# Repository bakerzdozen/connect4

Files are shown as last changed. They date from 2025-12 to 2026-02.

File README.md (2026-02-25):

# connect4

## About

4-in-a-line ("Connect 4" by Hasbro) is a popular two-player table game played with red and yellow chips for player 1 and player 2, respectively. It is played on a 7x6 board, where the objective is to connect four of your coloured chips in a row - be that horizontal, vertical or diagonal. 

This project aims to recreate the joy of 4-in-a-line with a modern twist, allowing for solo play against the "computer" (a very basic algorithm). Both the hardware and firmware are included in this repository to allow you to create your own variants or to make the exact same one yourself!

Originally, this project was a Christmas gift for my family and friends, but I have now made it open-source so anyone can make their own, or modify it to make it even better!

## Making Your Own

If you intend to create your own, you will need - at very least - the following:

- STM Cube IDE
- Pre-compiled firmware
- Fully assembled circuit board (I recommend JLC PCB)

## Improvements

If you have suggestions for how to make this project better, please let me know! The best way is through creating your own branch and making the modifications you see fit. If they are sensible and enhance the project in some meaningful way, I will be happy to merge your modifications to the main branch!

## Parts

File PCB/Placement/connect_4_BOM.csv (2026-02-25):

Designator | Qty | Comment | Footprint | JLC Part Number
C101,C102,C103,C106,C111,C112,C113,C115 | 8 | 4.7u | Capacitor_SMD:C_0603_1608Metric | C69335
C104 | 1 | 47u | Capacitor_SMD:C_1206_3216Metric | C403725
C105 | 1 | 10n | Capacitor_SMD:C_0603_1608Metric | C1589
C107,C108,C109,C110,C114,C201,C202,C301,C302,C401,C402,C501,C502,C601,C602,C701,C702,C801,C802 | 19 | 100n | Capacitor_SMD:C_0603_1608Metric | C1591
D101,D102 | 2 | LED | Diode_SMD:D_0603_1608Metric | C126319
D201,D202,D203,D204,D205,D206,D301,D302,D303,D304,D305,D306,D401,D402,D403,D404,D405,D406,D501,D502,D503,D504,D505,D506,D601,D602,D603,D604,D605,D606,D701,D702,D703,D704,D705,D706,D801,D802,D803,D804,D805,D806 | 42 | LED | Diode_SMD:D_0603_1608Metric | C79636
D207,D208,D209,D210,D211,D212,D307,D308,D309,D310,D311,D312,D407,D408,D409,D410,D411,D412,D507,D508,D509,D510,D511,D512,D607,D608,D609,D610,D611,D612,D707,D708,D709,D710,D711,D712,D807,D808,D809,D810,D811,D812 | 42 | LED | Diode_SMD:D_0603_1608Metric | C122984
J101 | 1 | USB4105-GF-A | Custom:USB4105_GCT | C2765186
R101,R102,R104,R105,R106,R107,R108,R109,R110 | 9 | 5.1k | Resistor_SMD:R_0603_1608Metric | C105580
R103,R111,R201,R202,R203,R204,R205,R206,R207,R208,R209,R210,R211,R212,R301,R302,R303,R304,R305,R306,R307,R308,R309,R310,R311,R312,R401,R402,R403,R404,R405,R406,R407,R408,R409,R410,R411,R412,R501,R502,R503,R504,R505,R506,R507,R508,R509,R510,R511,R512,R601,R602,R603,R604,R605,R606,R607,R608,R609,R610,R611,R612,R701,R702,R703,R704,R705,R706,R707,R708,R709,R710,R711,R712,R801,R802,R803,R804,R805,R806,R807,R808,R809,R810,R811,R812 | 86 | 1.2k | Resistor_SMD:R_0603_1608Metric | C114605
SW101,SW102,SW103,SW104 | 4 | SW_Push | Button_Switch_SMD:SW_Push_1P1T_NO_CK_KSC9xxG | C2837531
U101 | 1 | AMS1117-3.3 | Package_TO_SOT_SMD:SOT-223-3_TabPin2 | C6186
U102 | 1 | STM32G431CBTx | Package_QFP:LQFP-48_7x7mm_P0.5mm | C529355
U201,U202,U301,U302,U401,U402,U501,U502,U601,U602,U701,U702,U801,U802 | 14 | 74HC594 | Package_SO:SOIC-16W_7.5x10.3mm_P1.27mm | C91727

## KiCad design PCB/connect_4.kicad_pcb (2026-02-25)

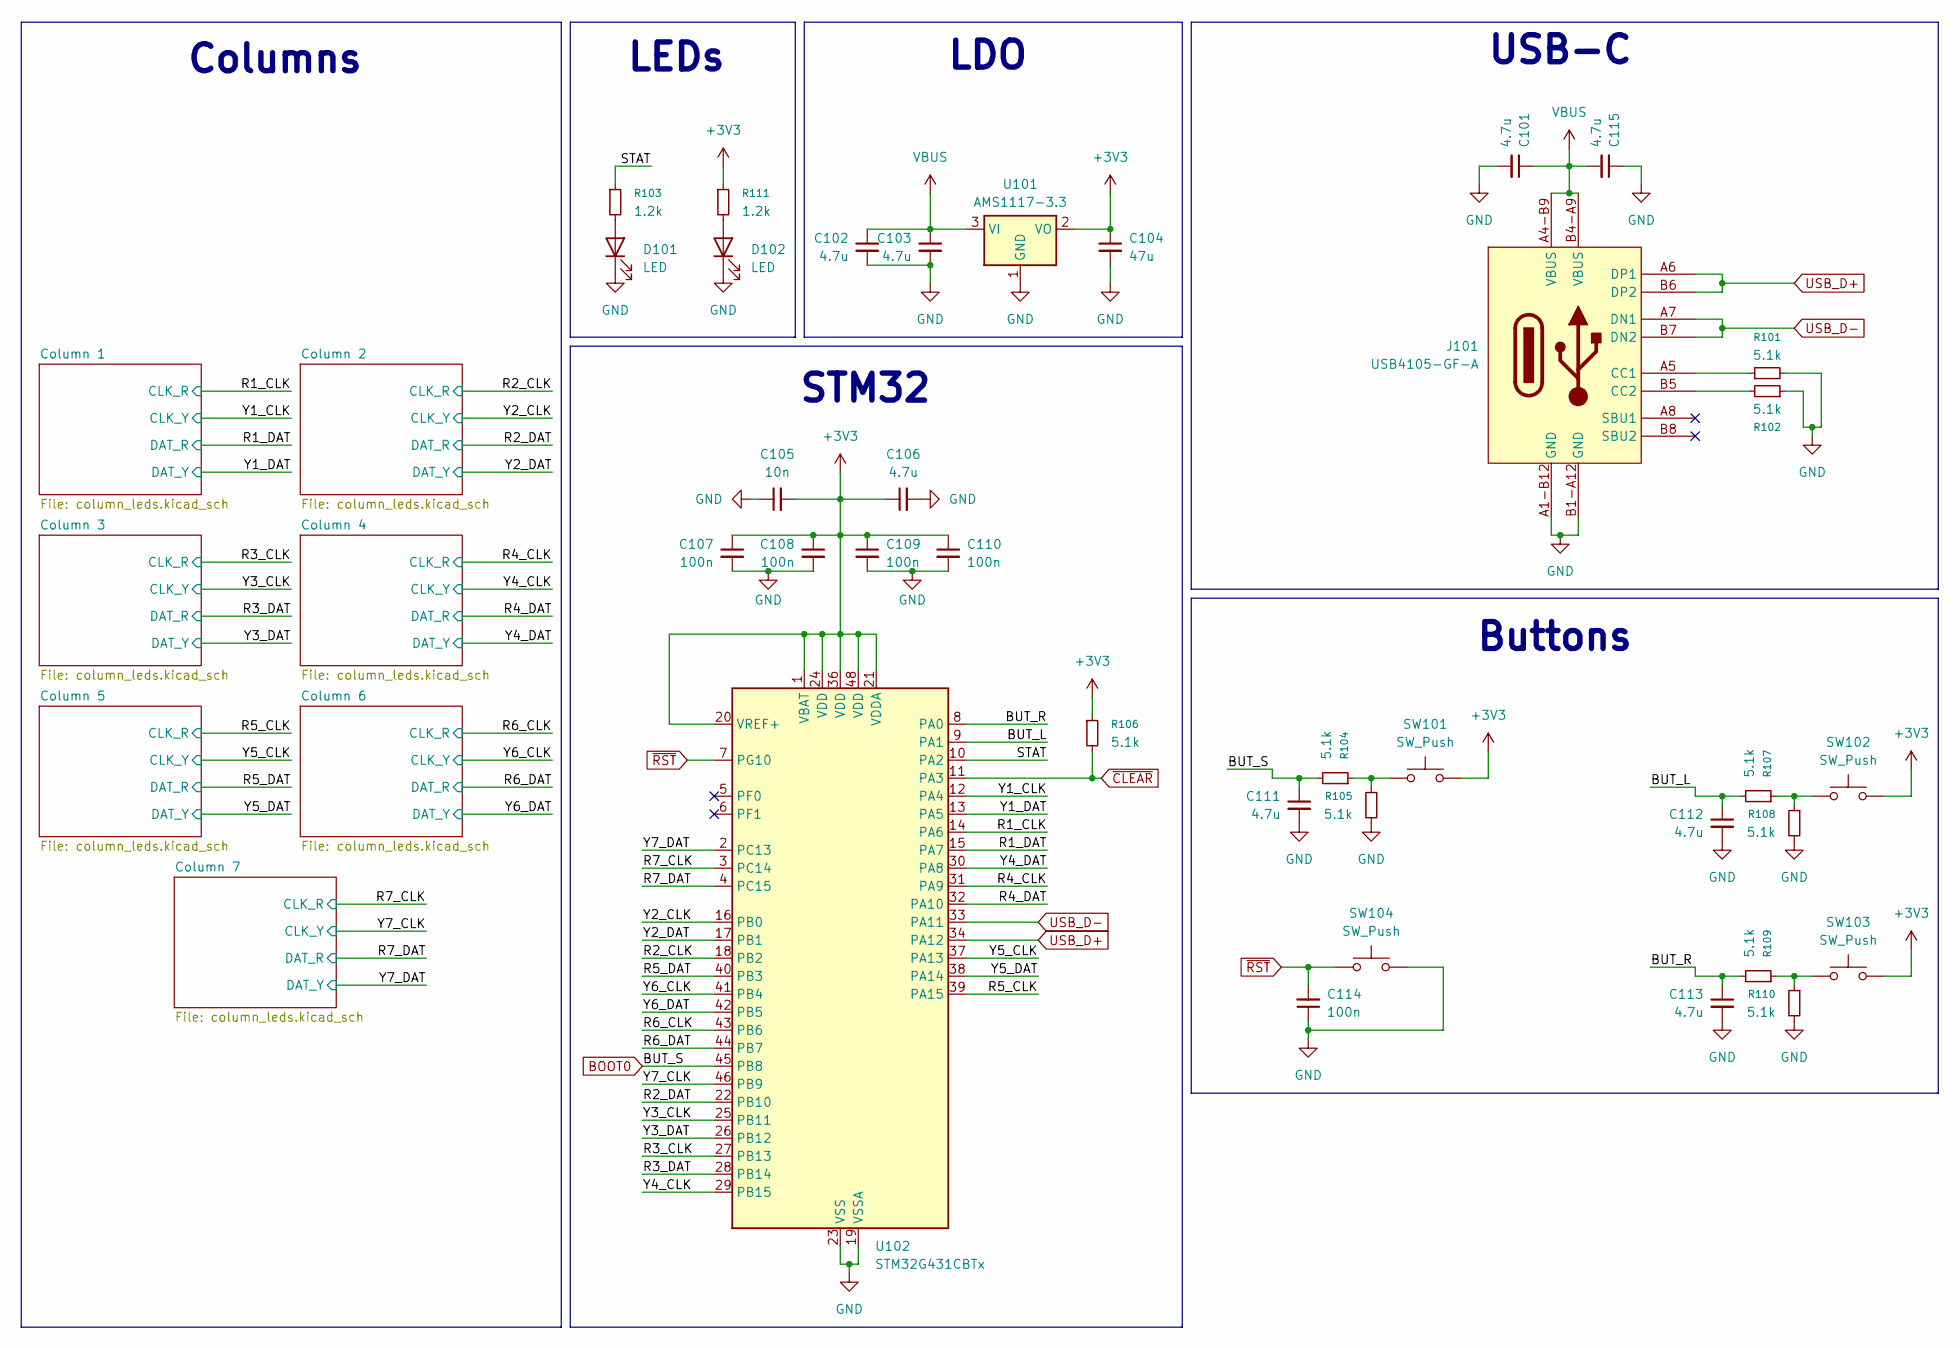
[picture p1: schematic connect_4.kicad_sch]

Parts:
C101, C102, C103, C106, C111, C112, C113, C115: 4.7u; C_0603_1608Metric; Manufacturer Part Number C69335
C104: 47u; C_1206_3216Metric; Manufacturer Part Number C403725
C105: 10n; C_0603_1608Metric; Manufacturer Part Number C1589
C107, C108, C109, C110, C114: 100n; C_0603_1608Metric; Manufacturer Part Number C1591
D101, D102: LED; D_0603_1608Metric; Manufacturer Part Number C126319
J101: USB4105-GF-A; USB4105_GCT; Manufacturer Part Number C2765186
R101, R102, R104, R105, R106, R107, R108, R109, R110: 5.1k; R_0603_1608Metric; Manufacturer Part Number C105580
R103, R111: 1.2k; R_0603_1608Metric; Manufacturer Part Number C114605
SW101, SW102, SW103, SW104: SW_Push; SW_Push_1P1T_NO_CK_KSC9xxG; Manufacturer Part Number C2837531
U101: AMS1117-3.3; SOT-223-3_TabPin2; Manufacturer Part Number C6186
U102: STM32G431CBTx; LQFP-48_7x7mm_P0.5mm; Manufacturer Part Number C529355

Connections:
+3V3: C104.1, C105.2, C106.1, C107.1, C108.1, C109.1, C110.1, R106.1, R111.1, SW101.2, SW102.2, SW103.2, U101.2 (VO), U102.1 (VBAT), U102.20 (VREF+), U102.21 (VDDA), U102.24 (VDD), U102.36 (VDD), U102.48 (VDD); also elsewhere on the board
/BUT_L: C112.1, R107.2, U102.9 (PA1)
/BUT_R: C113.1, R109.2, U102.8 (PA0)
/R1_CLK: U102.14 (PA6); also elsewhere on the board
/R1_DAT: U102.15 (PA7); also elsewhere on the board
/R2_CLK: U102.18 (PB2); also elsewhere on the board
/R2_DAT: U102.22 (PB10); also elsewhere on the board
/R3_CLK: U102.27 (PB13); also elsewhere on the board
/R3_DAT: U102.28 (PB14); also elsewhere on the board
/R4_CLK: U102.31 (PA9); also elsewhere on the board
/R4_DAT: U102.32 (PA10); also elsewhere on the board
/R5_CLK: U102.39 (PA15); also elsewhere on the board
/R5_DAT: U102.40 (PB3); also elsewhere on the board
/R6_CLK: U102.43 (PB6); also elsewhere on the board
/R6_DAT: U102.44 (PB7); also elsewhere on the board
/R7_CLK: U102.3 (PC14); also elsewhere on the board
/R7_DAT: U102.4 (PC15); also elsewhere on the board
/STAT: R103.1, U102.10 (PA2)
/Y1_CLK: U102.12 (PA4); also elsewhere on the board
/Y1_DAT: U102.13 (PA5); also elsewhere on the board
/Y2_CLK: U102.16 (PB0); also elsewhere on the board
/Y2_DAT: U102.17 (PB1); also elsewhere on the board
/Y3_CLK: U102.25 (PB11); also elsewhere on the board
/Y3_DAT: U102.26 (PB12); also elsewhere on the board
/Y4_CLK: U102.29 (PB15); also elsewhere on the board
/Y4_DAT: U102.30 (PA8); also elsewhere on the board
/Y5_CLK: U102.37 (PA13); also elsewhere on the board
/Y5_DAT: U102.38 (PA14); also elsewhere on the board
/Y6_CLK: U102.41 (PB4); also elsewhere on the board
/Y6_DAT: U102.42 (PB5); also elsewhere on the board
/Y7_CLK: U102.46 (PB9); also elsewhere on the board
/Y7_DAT: U102.2 (PC13); also elsewhere on the board
BOOT0: C111.1, R104.2, U102.45 (PB8)
GND: C101.2, C102.2, C103.2, C104.2, C105.1, C106.2, C107.2, C108.2, C109.2, C110.2, C111.2, C112.2, C113.2, C114.1, C115.1, D101.1 (K), D102.1 (K), J101.A1-B12 (GND), J101.B1-A12 (GND), R101.2, R102.1, R105.2, R108.2, R110.2, SW104.2, U101.1 (GND), U102.19 (VSSA), U102.23 (VSS), U102.35 (VSS), U102.47 (VSS); also elsewhere on the board
unnamed: D101.2 (A), R103.2
unnamed: D102.2 (A), R111.2
unnamed: J101.A5 (CC1), R101.1
unnamed: J101.B5 (CC2), R102.2
unnamed: R104.1, R105.1, SW101.1
unnamed: R107.1, R108.1, SW102.1
unnamed: R109.1, R110.1, SW103.1
USB_D+: J101.A6 (DP1), J101.B6 (DP2), U102.34 (PA12)
USB_D-: J101.A7 (DN1), J101.B7 (DN2), U102.33 (PA11)
VBUS: C101.1, C102.1, C103.1, C115.2, J101.A4-B9 (VBUS), J101.B4-A9 (VBUS), U101.3 (VI)
~CLEAR: R106.2, U102.11 (PA3); also elsewhere on the board
~RST: C114.2, SW104.1, U102.7 (PG10)

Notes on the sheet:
Buttons
USB-C
LDO
LEDs
STM32
Columns

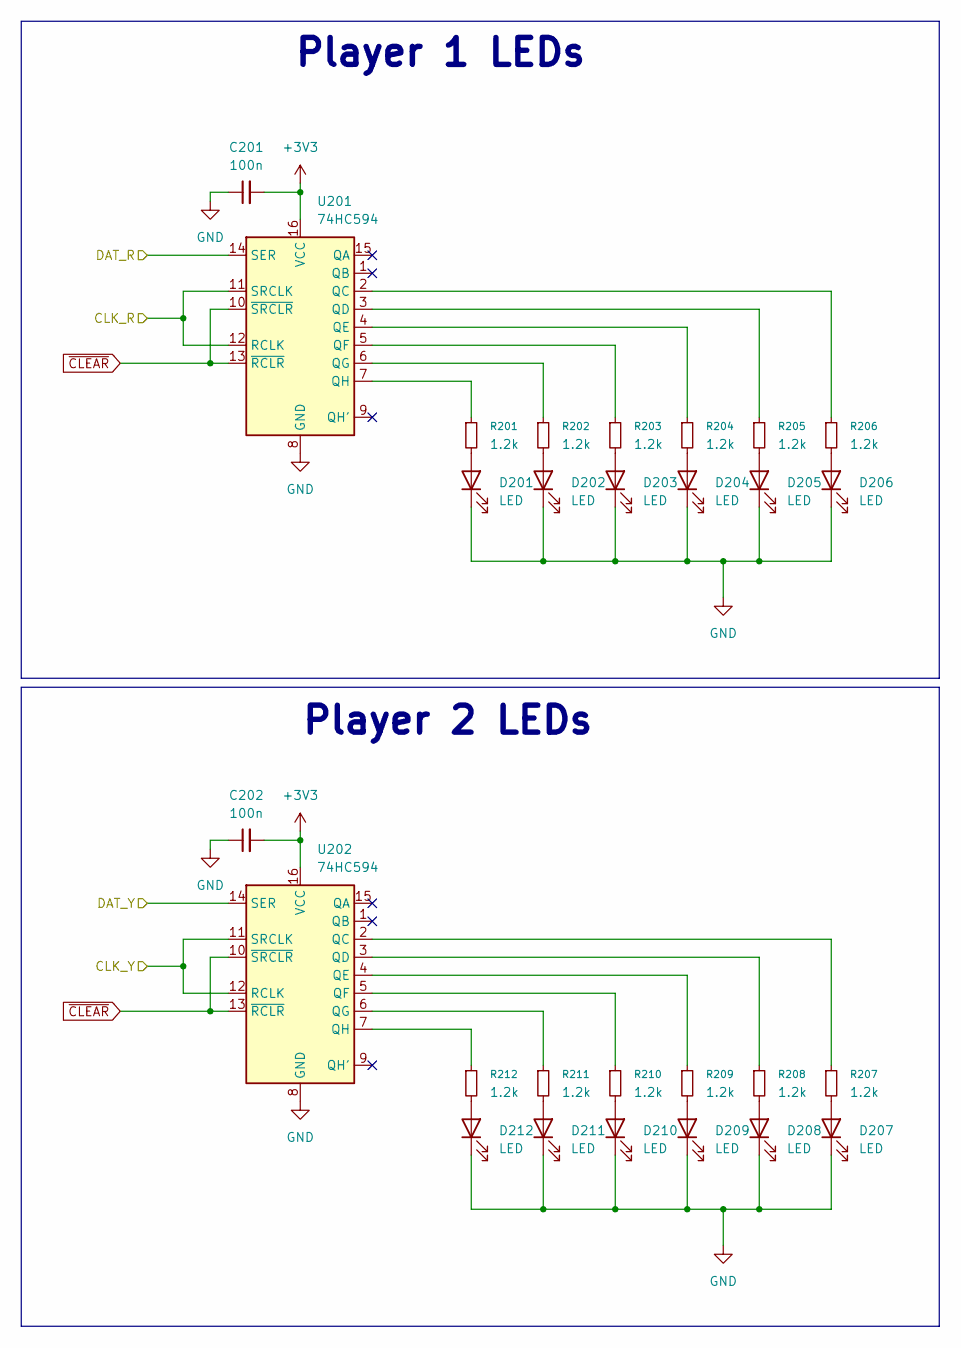
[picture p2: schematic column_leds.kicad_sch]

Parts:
C201, C202: 100n; C_0603_1608Metric; Manufacturer Part Number C1591
D201, D202, D203, D204, D205, D206: LED; D_0603_1608Metric; Manufacturer Part Number C79636
D207, D208, D209, D210, D211, D212: LED; D_0603_1608Metric; Manufacturer Part Number C122984
R201, R202, R203, R204, R205, R206, R207, R208, R209, R210, R211, R212: 1.2k; R_0603_1608Metric; Manufacturer Part Number C114605
U201, U202: 74HC594; SOIC-16W_5.3x10.2mm_P1.27mm; Manufacturer Part Number C91727

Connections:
+3V3: C201.2, C202.2, U201.16 (VCC), U202.16 (VCC); also elsewhere on the board
/R1_CLK: U201.11 (SRCLK), U201.12 (RCLK); also elsewhere on the board
/R1_DAT: U201.14 (SER); also elsewhere on the board
/Y1_CLK: U202.11 (SRCLK), U202.12 (RCLK); also elsewhere on the board
/Y1_DAT: U202.14 (SER); also elsewhere on the board
GND: C201.1, C202.1, D201.1 (K), D202.1 (K), D203.1 (K), D204.1 (K), D205.1 (K), D206.1 (K), D207.1 (K), D208.1 (K), D209.1 (K), D210.1 (K), D211.1 (K), D212.1 (K), U201.8 (GND), U202.8 (GND); also elsewhere on the board
unnamed: D201.2 (A), R201.2
unnamed: D202.2 (A), R202.2
unnamed: D203.2 (A), R203.2
unnamed: D204.2 (A), R204.2
unnamed: D205.2 (A), R205.2
unnamed: D206.2 (A), R206.2
unnamed: D207.2 (A), R207.2
unnamed: D208.2 (A), R208.2
unnamed: D209.2 (A), R209.2
unnamed: D210.2 (A), R210.2
unnamed: D211.2 (A), R211.2
unnamed: D212.2 (A), R212.2
unnamed: R206.1, U201.2 (QC)
unnamed: R205.1, U201.3 (QD)
unnamed: R204.1, U201.4 (QE)
unnamed: R203.1, U201.5 (QF)
unnamed: R202.1, U201.6 (QG)
unnamed: R201.1, U201.7 (QH)
unnamed: R207.1, U202.2 (QC)
unnamed: R208.1, U202.3 (QD)
unnamed: R209.1, U202.4 (QE)
unnamed: R210.1, U202.5 (QF)
unnamed: R211.1, U202.6 (QG)
unnamed: R212.1, U202.7 (QH)
~CLEAR: U201.10 (~SRCLR), U201.13 (~RCLR), U202.10 (~SRCLR), U202.13 (~RCLR); also elsewhere on the board

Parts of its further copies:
C301, C302, C401, C402, C501, C502, C601, C602, C701, C702, C801, C802: 100n; C_0603_1608Metric; Manufacturer Part Number C1591
D301, D302, D303, D304, D305, D306, D401, D402, D403, D404, D405, D406, D501, D502, D503, D504, D505, D506, D601, D602, D603, D604, D605, D606, D701, D702, D703, D704, D705, D706, D801, D802, D803, D804, D805, D806: LED; D_0603_1608Metric; Manufacturer Part Number C79636
D307, D308, D309, D310, D311, D312, D407, D408, D409, D410, D411, D412, D507, D508, D509, D510, D511, D512, D607, D608, D609, D610, D611, D612, D707, D708, D709, D710, D711, D712, D807, D808, D809, D810, D811, D812: LED; D_0603_1608Metric; Manufacturer Part Number C122984
R301, R302, R303, R304, R305, R306, R307, R308, R309, R310, R311, R312, R401, R402, R403, R404, R405, R406, R407, R408, R409, R410, R411, R412, R501, R502, R503, R504, R505, R506, R507, R508, R509, R510, R511, R512, R601, R602, R603, R604, R605, R606, R607, R608, R609, R610, R611, R612, R701, R702, R703, R704, R705, R706, R707, R708, R709, R710, R711, R712, R801, R802, R803, R804, R805, R806, R807, R808, R809, R810, R811, R812: 1.2k; R_0603_1608Metric; Manufacturer Part Number C114605
U301, U302, U401, U402, U501, U502, U601, U602, U701, U702, U801, U802: 74HC594; SOIC-16W_5.3x10.2mm_P1.27mm; Manufacturer Part Number C91727

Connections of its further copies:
+3V3: C301.2, C302.2, C401.2, C402.2, C501.2, C502.2, C601.2, C602.2, C701.2, C702.2, C801.2, C802.2, U301.16 (VCC), U302.16 (VCC), U401.16 (VCC), U402.16 (VCC), U501.16 (VCC), U502.16 (VCC), U601.16 (VCC), U602.16 (VCC), U701.16 (VCC), U702.16 (VCC), U801.16 (VCC), U802.16 (VCC); also elsewhere on the board
/R2_CLK: U301.11 (SRCLK), U301.12 (RCLK); also elsewhere on the board
/R2_DAT: U301.14 (SER); also elsewhere on the board
/R3_CLK: U401.11 (SRCLK), U401.12 (RCLK); also elsewhere on the board
/R3_DAT: U401.14 (SER); also elsewhere on the board
/R4_CLK: U501.11 (SRCLK), U501.12 (RCLK); also elsewhere on the board
/R4_DAT: U501.14 (SER); also elsewhere on the board
/R5_CLK: U601.11 (SRCLK), U601.12 (RCLK); also elsewhere on the board
/R5_DAT: U601.14 (SER); also elsewhere on the board
/R6_CLK: U701.11 (SRCLK), U701.12 (RCLK); also elsewhere on the board
/R6_DAT: U701.14 (SER); also elsewhere on the board
/R7_CLK: U801.11 (SRCLK), U801.12 (RCLK); also elsewhere on the board
/R7_DAT: U801.14 (SER); also elsewhere on the board
/Y2_CLK: U302.11 (SRCLK), U302.12 (RCLK); also elsewhere on the board
/Y2_DAT: U302.14 (SER); also elsewhere on the board
/Y3_CLK: U402.11 (SRCLK), U402.12 (RCLK); also elsewhere on the board
/Y3_DAT: U402.14 (SER); also elsewhere on the board
/Y4_CLK: U502.11 (SRCLK), U502.12 (RCLK); also elsewhere on the board
/Y4_DAT: U502.14 (SER); also elsewhere on the board
/Y5_CLK: U602.11 (SRCLK), U602.12 (RCLK); also elsewhere on the board
/Y5_DAT: U602.14 (SER); also elsewhere on the board
/Y6_CLK: U702.11 (SRCLK), U702.12 (RCLK); also elsewhere on the board
/Y6_DAT: U702.14 (SER); also elsewhere on the board
/Y7_CLK: U802.11 (SRCLK), U802.12 (RCLK); also elsewhere on the board
/Y7_DAT: U802.14 (SER); also elsewhere on the board
GND: C301.1, C302.1, C401.1, C402.1, C501.1, C502.1, C601.1, C602.1, C701.1, C702.1, C801.1, C802.1, D301.1 (K), D302.1 (K), D303.1 (K), D304.1 (K), D305.1 (K), D306.1 (K), D307.1 (K), D308.1 (K), D309.1 (K), D310.1 (K), D311.1 (K), D312.1 (K), D401.1 (K), D402.1 (K), D403.1 (K), D404.1 (K), D405.1 (K), D406.1 (K), D407.1 (K), D408.1 (K), D409.1 (K), D410.1 (K), D411.1 (K), D412.1 (K), D501.1 (K), D502.1 (K), D503.1 (K), D504.1 (K), D505.1 (K), D506.1 (K), D507.1 (K), D508.1 (K), D509.1 (K), D510.1 (K), D511.1 (K), D512.1 (K), D601.1 (K), D602.1 (K), D603.1 (K), D604.1 (K), D605.1 (K), D606.1 (K), D607.1 (K), D608.1 (K), D609.1 (K), D610.1 (K), D611.1 (K), D612.1 (K), D701.1 (K), D702.1 (K), D703.1 (K), D704.1 (K), D705.1 (K), D706.1 (K), D707.1 (K), D708.1 (K), D709.1 (K), D710.1 (K), D711.1 (K), D712.1 (K), D801.1 (K), D802.1 (K), D803.1 (K), D804.1 (K), D805.1 (K), D806.1 (K), D807.1 (K), D808.1 (K), D809.1 (K), D810.1 (K), D811.1 (K), D812.1 (K), U301.8 (GND), U302.8 (GND), U401.8 (GND), U402.8 (GND), U501.8 (GND), U502.8 (GND), U601.8 (GND), U602.8 (GND), U701.8 (GND), U702.8 (GND), U801.8 (GND), U802.8 (GND); also elsewhere on the board
unnamed: D301.2 (A), R301.2
unnamed: D302.2 (A), R302.2
unnamed: D303.2 (A), R303.2
unnamed: D304.2 (A), R304.2
unnamed: D305.2 (A), R305.2
unnamed: D306.2 (A), R306.2
unnamed: D307.2 (A), R307.2
unnamed: D308.2 (A), R308.2
unnamed: D309.2 (A), R309.2
unnamed: D310.2 (A), R310.2
unnamed: D311.2 (A), R311.2
unnamed: D312.2 (A), R312.2
unnamed: D401.2 (A), R401.2
unnamed: D402.2 (A), R402.2
unnamed: D403.2 (A), R403.2
unnamed: D404.2 (A), R404.2
unnamed: D405.2 (A), R405.2
unnamed: D406.2 (A), R406.2
unnamed: D407.2 (A), R407.2
unnamed: D408.2 (A), R408.2
unnamed: D409.2 (A), R409.2
unnamed: D410.2 (A), R410.2
unnamed: D411.2 (A), R411.2
unnamed: D412.2 (A), R412.2
unnamed: D501.2 (A), R501.2
unnamed: D502.2 (A), R502.2
unnamed: D503.2 (A), R503.2
unnamed: D504.2 (A), R504.2
unnamed: D505.2 (A), R505.2
unnamed: D506.2 (A), R506.2
unnamed: D507.2 (A), R507.2
unnamed: D508.2 (A), R508.2
unnamed: D509.2 (A), R509.2
unnamed: D510.2 (A), R510.2
unnamed: D511.2 (A), R511.2
unnamed: D512.2 (A), R512.2
unnamed: D601.2 (A), R601.2
unnamed: D602.2 (A), R602.2
unnamed: D603.2 (A), R603.2
unnamed: D604.2 (A), R604.2
unnamed: D605.2 (A), R605.2
unnamed: D606.2 (A), R606.2
unnamed: D607.2 (A), R607.2
unnamed: D608.2 (A), R608.2
unnamed: D609.2 (A), R609.2
unnamed: D610.2 (A), R610.2
unnamed: D611.2 (A), R611.2
unnamed: D612.2 (A), R612.2
unnamed: D701.2 (A), R701.2
unnamed: D702.2 (A), R702.2
unnamed: D703.2 (A), R703.2
unnamed: D704.2 (A), R704.2
unnamed: D705.2 (A), R705.2
unnamed: D706.2 (A), R706.2
unnamed: D707.2 (A), R707.2
unnamed: D708.2 (A), R708.2
unnamed: D709.2 (A), R709.2
unnamed: D710.2 (A), R710.2
unnamed: D711.2 (A), R711.2
unnamed: D712.2 (A), R712.2
unnamed: D801.2 (A), R801.2
unnamed: D802.2 (A), R802.2
unnamed: D803.2 (A), R803.2
unnamed: D804.2 (A), R804.2
unnamed: D805.2 (A), R805.2
unnamed: D806.2 (A), R806.2
unnamed: D807.2 (A), R807.2
unnamed: D808.2 (A), R808.2
unnamed: D809.2 (A), R809.2
unnamed: D810.2 (A), R810.2
unnamed: D811.2 (A), R811.2
unnamed: D812.2 (A), R812.2
unnamed: R306.1, U301.2 (QC)
unnamed: R305.1, U301.3 (QD)
unnamed: R304.1, U301.4 (QE)
unnamed: R303.1, U301.5 (QF)
unnamed: R302.1, U301.6 (QG)
unnamed: R301.1, U301.7 (QH)
unnamed: R307.1, U302.2 (QC)
unnamed: R308.1, U302.3 (QD)
unnamed: R309.1, U302.4 (QE)
unnamed: R310.1, U302.5 (QF)
unnamed: R311.1, U302.6 (QG)
unnamed: R312.1, U302.7 (QH)
unnamed: R406.1, U401.2 (QC)
unnamed: R405.1, U401.3 (QD)
unnamed: R404.1, U401.4 (QE)
unnamed: R403.1, U401.5 (QF)
unnamed: R402.1, U401.6 (QG)
unnamed: R401.1, U401.7 (QH)
unnamed: R407.1, U402.2 (QC)
unnamed: R408.1, U402.3 (QD)
unnamed: R409.1, U402.4 (QE)
unnamed: R410.1, U402.5 (QF)
unnamed: R411.1, U402.6 (QG)
unnamed: R412.1, U402.7 (QH)
unnamed: R506.1, U501.2 (QC)
unnamed: R505.1, U501.3 (QD)
unnamed: R504.1, U501.4 (QE)
unnamed: R503.1, U501.5 (QF)
unnamed: R502.1, U501.6 (QG)
unnamed: R501.1, U501.7 (QH)
unnamed: R507.1, U502.2 (QC)
unnamed: R508.1, U502.3 (QD)
unnamed: R509.1, U502.4 (QE)
unnamed: R510.1, U502.5 (QF)
unnamed: R511.1, U502.6 (QG)
unnamed: R512.1, U502.7 (QH)
unnamed: R606.1, U601.2 (QC)
unnamed: R605.1, U601.3 (QD)
unnamed: R604.1, U601.4 (QE)
unnamed: R603.1, U601.5 (QF)
unnamed: R602.1, U601.6 (QG)
unnamed: R601.1, U601.7 (QH)
unnamed: R607.1, U602.2 (QC)
unnamed: R608.1, U602.3 (QD)
unnamed: R609.1, U602.4 (QE)
unnamed: R610.1, U602.5 (QF)
unnamed: R611.1, U602.6 (QG)
unnamed: R612.1, U602.7 (QH)
unnamed: R706.1, U701.2 (QC)
unnamed: R705.1, U701.3 (QD)
unnamed: R704.1, U701.4 (QE)
unnamed: R703.1, U701.5 (QF)
unnamed: R702.1, U701.6 (QG)
unnamed: R701.1, U701.7 (QH)
unnamed: R707.1, U702.2 (QC)
unnamed: R708.1, U702.3 (QD)
unnamed: R709.1, U702.4 (QE)
unnamed: R710.1, U702.5 (QF)
unnamed: R711.1, U702.6 (QG)
unnamed: R712.1, U702.7 (QH)
unnamed: R806.1, U801.2 (QC)
unnamed: R805.1, U801.3 (QD)
unnamed: R804.1, U801.4 (QE)
unnamed: R803.1, U801.5 (QF)
unnamed: R802.1, U801.6 (QG)
unnamed: R801.1, U801.7 (QH)
unnamed: R807.1, U802.2 (QC)
unnamed: R808.1, U802.3 (QD)
unnamed: R809.1, U802.4 (QE)
unnamed: R810.1, U802.5 (QF)
unnamed: R811.1, U802.6 (QG)
unnamed: R812.1, U802.7 (QH)
~CLEAR: U301.10 (~SRCLR), U301.13 (~RCLR), U302.10 (~SRCLR), U302.13 (~RCLR), U401.10 (~SRCLR), U401.13 (~RCLR), U402.10 (~SRCLR), U402.13 (~RCLR), U501.10 (~SRCLR), U501.13 (~RCLR), U502.10 (~SRCLR), U502.13 (~RCLR), U601.10 (~SRCLR), U601.13 (~RCLR), U602.10 (~SRCLR), U602.13 (~RCLR), U701.10 (~SRCLR), U701.13 (~RCLR), U702.10 (~SRCLR), U702.13 (~RCLR), U801.10 (~SRCLR), U801.13 (~RCLR), U802.10 (~SRCLR), U802.13 (~RCLR); also elsewhere on the board

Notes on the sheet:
Player 2 LEDs
Player 1 LEDs

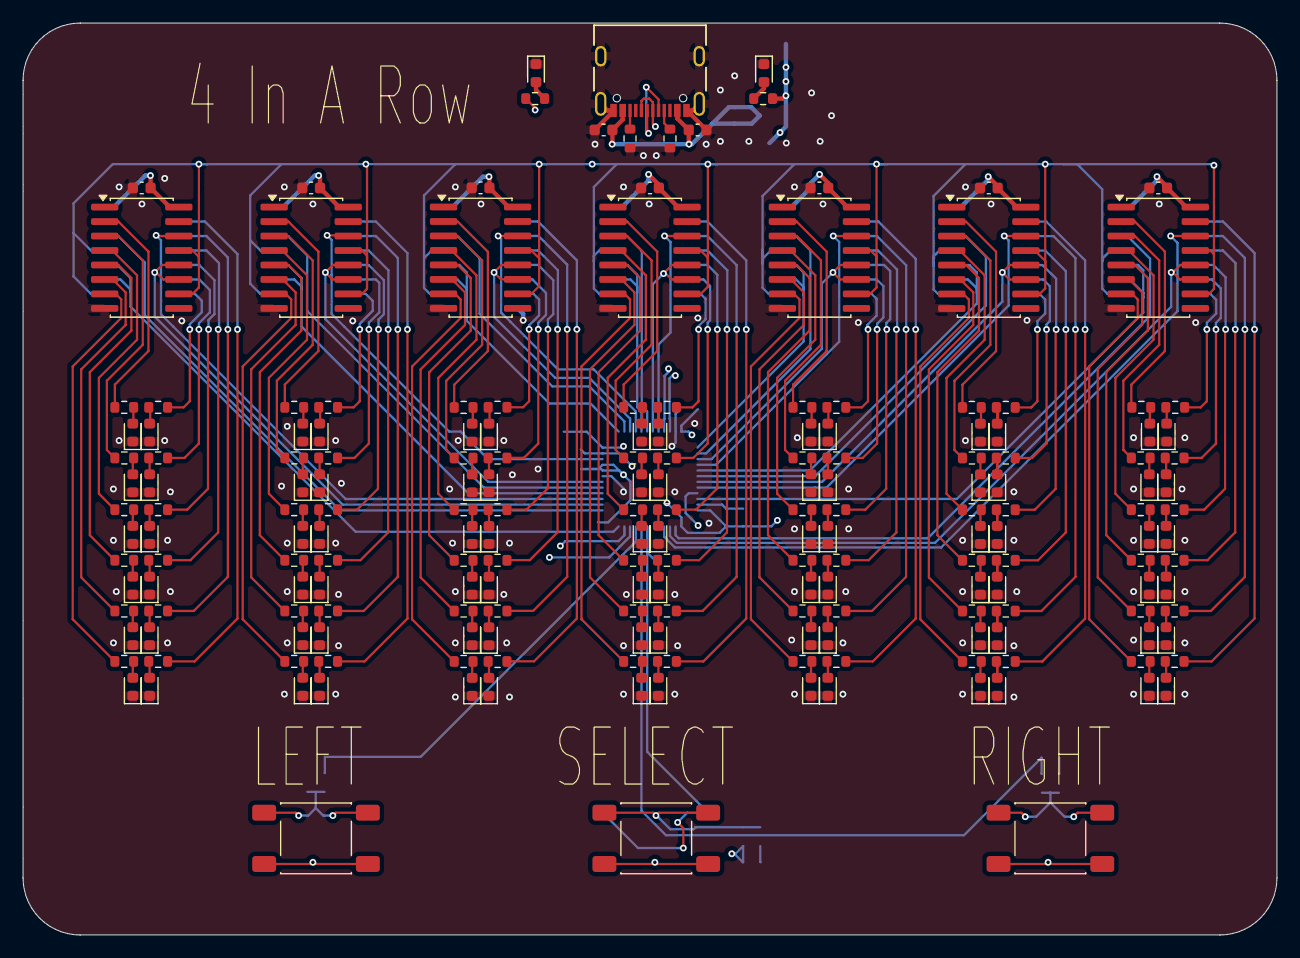
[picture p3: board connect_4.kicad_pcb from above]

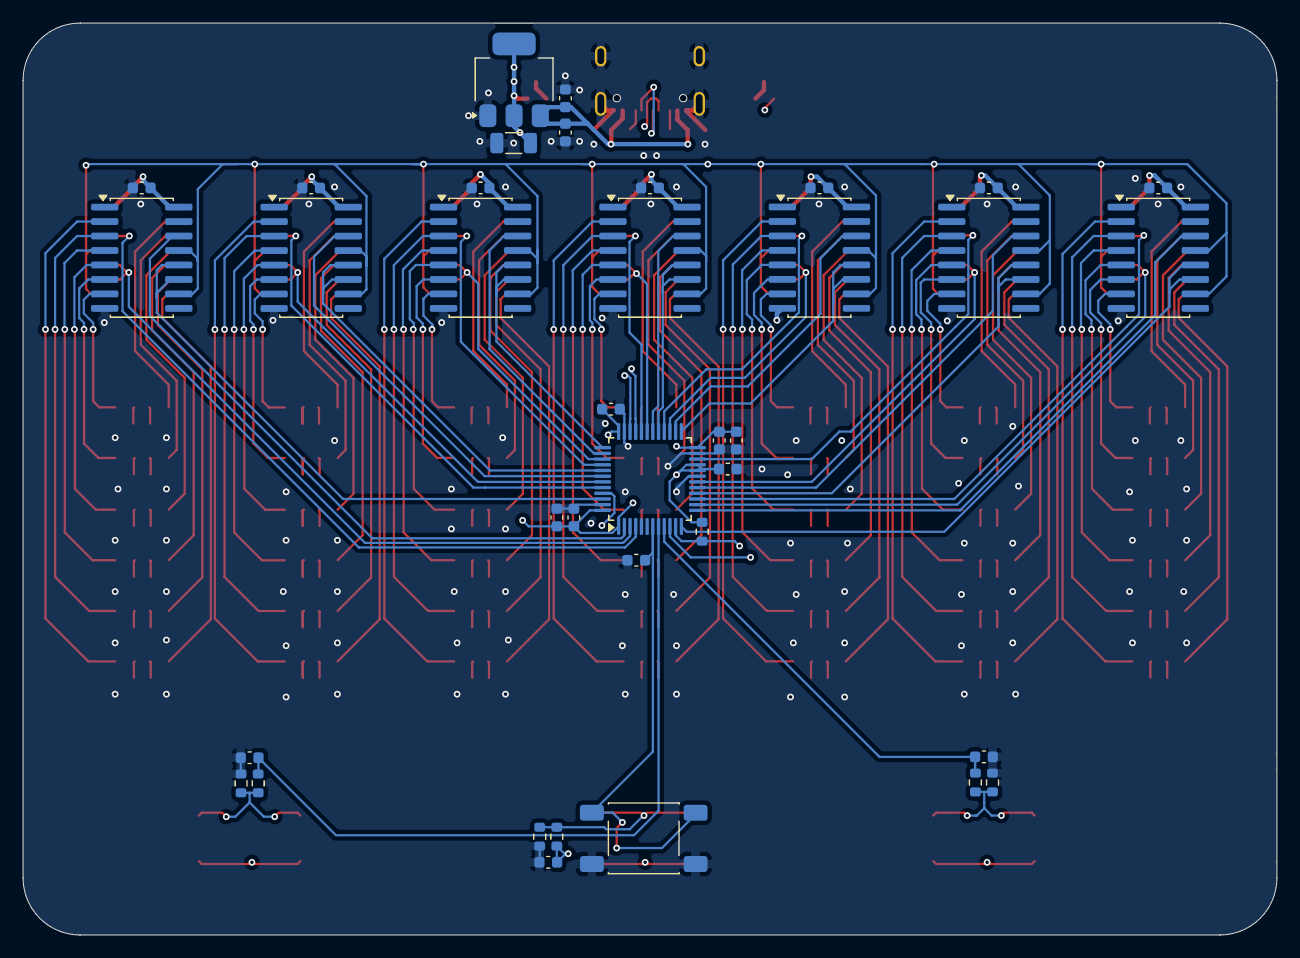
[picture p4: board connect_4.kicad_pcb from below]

Board: 4 copper layers, 110.0 x 80.0 mm, 231 parts (37 on the bottom side), 214 nets.

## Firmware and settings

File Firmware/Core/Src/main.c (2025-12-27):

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
/* Includes ------------------------------------------------------------------*/
#include "main.h"
#include <stdint.h>
#include <stdbool.h>

/* USER CODE BEGIN Includes */
#include "core_cm4.h"
/* USER CODE END Includes */

PCD_HandleTypeDef hpcd_USB_FS;

/* USER CODE BEGIN PV */
#define LED_ROWS			6
#define LED_COLS			7
#define LED_COUNT			(LED_ROWS * LED_COLS)

typedef enum _led_mode {
	LED_OFF,
	LED_PLAYER1,
	LED_PLAYER2,
	LED_BOTH
} ledMode_t;

typedef enum _game_state {
	GAME_INIT,
	GAME_PLAYER1,
	GAME_PLAYER2,
	GAME_WIN_PLAYER1,
	GAME_WIN_PLAYER2,
	GAME_DRAW
} gameState_t;

typedef struct _col_driver {
	GPIO_TypeDef* dat2Port;
	GPIO_TypeDef* dat1Port;
	GPIO_TypeDef* clk2Port;
	GPIO_TypeDef* clk1Port;
	uint16_t dat1Pin;
	uint16_t dat2Pin;
	uint16_t clk1Pin;
	uint16_t clk2Pin;
} colDriver_t;

typedef struct _pos {
	uint8_t col;
	uint8_t row;
} pos_t;

#define HUMAN_PLAYER		LED_PLAYER1
#define COMPUTER_PLAYER		LED_PLAYER2

ledMode_t leds[LED_COUNT] = {0};
colDriver_t column_drivers[LED_COLS] = {0};

pos_t winning_pieces[7];
uint8_t winning_pieces_count = 0;

const int8_t ROW_DELTA[] = {-1, -1, 0, 1};
const int8_t COL_DELTA[] = {0, 1, 1, 1};
/* USER CODE END PV */

void SystemClock_Config(void);
static void MX_GPIO_Init(void);
static void MX_USB_PCD_Init(void);
/* USER CODE BEGIN 0 */

static void driver_init()
{
	// Column 1
	// Ports
	column_drivers[0].clk1Port = GPIOA;
	column_drivers[0].dat1Port = GPIOA;
	column_drivers[0].clk2Port = GPIOA;
	column_drivers[0].dat2Port = GPIOA;
	// Pins
	column_drivers[0].clk1Pin = GPIO_PIN_4;
	column_drivers[0].dat1Pin = GPIO_PIN_5;
	column_drivers[0].clk2Pin = GPIO_PIN_6;
	column_drivers[0].dat2Pin = GPIO_PIN_7;

	// Column 2
	// Ports
	column_drivers[1].clk1Port = GPIOB;
	column_drivers[1].dat1Port = GPIOB;
	column_drivers[1].clk2Port = GPIOB;
	column_drivers[1].dat2Port = GPIOB;
	// Pins
	column_drivers[1].clk1Pin = GPIO_PIN_0;
	column_drivers[1].dat1Pin = GPIO_PIN_1;
	column_drivers[1].clk2Pin = GPIO_PIN_2;
	column_drivers[1].dat2Pin = GPIO_PIN_10;

	// Column 3
	// Ports
	column_drivers[2].clk1Port = GPIOB;
	column_drivers[2].dat1Port = GPIOB;
	column_drivers[2].clk2Port = GPIOB;
	column_drivers[2].dat2Port = GPIOB;
	// Pins
	column_drivers[2].clk1Pin = GPIO_PIN_11;
	column_drivers[2].dat1Pin = GPIO_PIN_12;
	column_drivers[2].clk2Pin = GPIO_PIN_13;
	column_drivers[2].dat2Pin = GPIO_PIN_14;

	// Column 4
	// Ports
	column_drivers[3].clk1Port = GPIOB;
	column_drivers[3].dat1Port = GPIOA;
	column_drivers[3].clk2Port = GPIOA;
	column_drivers[3].dat2Port = GPIOA;
	// Pins
	column_drivers[3].clk1Pin = GPIO_PIN_15;
	column_drivers[3].dat1Pin = GPIO_PIN_8;
	column_drivers[3].clk2Pin = GPIO_PIN_9;
	column_drivers[3].dat2Pin = GPIO_PIN_10;

	// Column 5
	// Ports
	column_drivers[4].clk1Port = GPIOA;
	column_drivers[4].dat1Port = GPIOA;
	column_drivers[4].clk2Port = GPIOA;
	column_drivers[4].dat2Port = GPIOB;
	// Pins
	column_drivers[4].clk1Pin = GPIO_PIN_13;
	column_drivers[4].dat1Pin = GPIO_PIN_14;
	column_drivers[4].clk2Pin = GPIO_PIN_15;
	column_drivers[4].dat2Pin = GPIO_PIN_3;

	// Column 6
	// Ports
	column_drivers[5].clk1Port = GPIOB;
	column_drivers[5].dat1Port = GPIOB;
	column_drivers[5].clk2Port = GPIOB;
	column_drivers[5].dat2Port = GPIOB;
	// Pins
	column_drivers[5].clk1Pin = GPIO_PIN_4;
	column_drivers[5].dat1Pin = GPIO_PIN_5;
	column_drivers[5].clk2Pin = GPIO_PIN_6;
	column_drivers[5].dat2Pin = GPIO_PIN_7;

	// Column 7
	// Ports
	column_drivers[6].clk1Port = GPIOB;
	column_drivers[6].dat1Port = GPIOC;
	column_drivers[6].clk2Port = GPIOC;
	column_drivers[6].dat2Port = GPIOC;
	// Pins
	column_drivers[6].clk1Pin = GPIO_PIN_9;
	column_drivers[6].dat1Pin = GPIO_PIN_13;
	column_drivers[6].clk2Pin = GPIO_PIN_14;
	column_drivers[6].dat2Pin = GPIO_PIN_15;
//
//	// Set all clocks to HIGH
//	for (uint8_t col = 0; col < LED_COLS; col++) {
//		HAL_GPIO_TogglePin(column_drivers[col].clk1Port, column_drivers[col].clk1Pin);
//		HAL_GPIO_TogglePin(column_drivers[col].clk2Port, column_drivers[col].clk2Pin);
//	}

	// Set the ENABLE line to high
	HAL_GPIO_WritePin(GPIOA, GPIO_PIN_3, GPIO_PIN_SET);
}

static void output_col(uint8_t col_no)
{
	colDriver_t driver = column_drivers[col_no];

	uint8_t row = 0;

	for (; row < LED_ROWS; row++) {
		// Set the data then pulse the clock
		ledMode_t p1stat = leds[row * LED_COLS + col_no];
		ledMode_t p2stat = leds[((LED_ROWS - 1) - row) * LED_COLS + col_no];

		// No output for either
		HAL_GPIO_WritePin(driver.dat1Port, driver.dat1Pin, p1stat == LED_PLAYER1);
		HAL_GPIO_WritePin(driver.dat2Port, driver.dat2Pin, p2stat == LED_PLAYER2);

		HAL_GPIO_TogglePin(driver.clk1Port, driver.clk1Pin);
		HAL_GPIO_TogglePin(driver.clk2Port, driver.clk2Pin);

		HAL_GPIO_TogglePin(driver.clk1Port, driver.clk1Pin);
		HAL_GPIO_TogglePin(driver.clk2Port, driver.clk2Pin);
	}

	while (row++ <= 8) {

		HAL_GPIO_TogglePin(driver.clk1Port, driver.clk1Pin);
		HAL_GPIO_TogglePin(driver.clk2Port, driver.clk2Pin);

		HAL_GPIO_TogglePin(driver.clk1Port, driver.clk1Pin);
		HAL_GPIO_TogglePin(driver.clk2Port, driver.clk2Pin);
	}
}

void place_piece(ledMode_t player, uint8_t col_no)
{
	if (col_no >= LED_COLS) {
		return;
	}

	// Start at row 0 and increment until there is already a piece
	uint8_t row = 0;

	for (; row < LED_ROWS; row++) {
		ledMode_t state = leds[row * LED_COLS + col_no];

		if (state != LED_OFF) {
			break;
		} else if (row > 0) {
			// Remove previous LED
			leds[(row - 1) * LED_COLS + col_no] = LED_OFF;
		}

		leds[row * LED_COLS + col_no] = player;

		// Update column
		output_col(col_no);

		HAL_Delay(500);
	}
}

int8_t get_next_row(uint8_t col)
{
	int8_t row = (LED_ROWS - 1);

	for (; row >= 0; row--) {
		if (leds[row * LED_COLS + col] == LED_OFF) {
			break;
		}
	}
	return row;
}

void set_winning_pieces(ledMode_t player, uint8_t col) {
	// We need to find the direction of the winning pieces
	uint8_t max = 0;
	uint8_t dir_pos = 0;

	int8_t row = get_next_row(col);

	if (row < 0) {
		row = 0;
	} else if (row < (LED_ROWS - 1)) {
		row++;
	}

	for (uint8_t dir = 0; dir < sizeof(ROW_DELTA); dir++) {
		int8_t dRow = ROW_DELTA[dir];
		int8_t dCol = COL_DELTA[dir];

		int8_t currRow = row + dRow;
		int8_t currCol = col + dCol;

		// Loop until last matching piece
		while ((currRow < LED_ROWS) && (currRow >= 0) &&
			   (currCol < LED_COLS) && (currCol >= 0)) {
			if (leds[currRow * LED_COLS + currCol] != player) {
				break;
			}

			currRow += dRow;
			currCol += dCol;
		}

		// Decrease currRow & currCol to last known position
		currRow -= dRow;
		currCol -= dCol;

		dRow = -dRow;
		dCol = -dCol;

		uint8_t continuous = 0;

		while ((currRow < LED_ROWS) && (currRow >= 0) &&
			   (currCol < LED_COLS) && (currCol >= 0)) {

			if (leds[currRow * LED_COLS + currCol] != player) {
				break;
			}

			continuous++;

			currRow += dRow;
			currCol += dCol;
		}

		if (continuous > max) {
			max = continuous;
			dir_pos = dir;
		}
	}

	int8_t dRow = ROW_DELTA[dir_pos];
	int8_t dCol = COL_DELTA[dir_pos];

	int8_t currRow = row + dRow;
	int8_t currCol = col + dCol;

	// Loop until last matching piece
	while ((currRow < LED_ROWS) && (currRow >= 0) &&
		   (currCol < LED_COLS) && (currCol >= 0)) {
		if (leds[currRow * LED_COLS + currCol] != player) {
			break;
		}

		currRow += dRow;
		currCol += dCol;
	}

	// Decrease currRow & currCol to last known position
	currRow -= dRow;
	currCol -= dCol;

	dRow = -dRow;
	dCol = -dCol;

	winning_pieces_count = 0;

	while ((currRow < LED_ROWS) && (currRow >= 0) &&
		   (currCol < LED_COLS) && (currCol >= 0)) {

		if (leds[currRow * LED_COLS + currCol] != player) {
			break;
		}

		winning_pieces[winning_pieces_count].col = currCol;
		winning_pieces[winning_pieces_count++].row = currRow;

		currRow += dRow;
		currCol += dCol;
	}
}

uint8_t eval_position(ledMode_t player, uint8_t col, uint8_t row) {
	ledMode_t opposite = (player == LED_PLAYER1) ? LED_PLAYER2 : LED_PLAYER1;

	uint8_t max = 0;

	for (uint8_t dir = 0; dir < sizeof(ROW_DELTA); dir++) {
		int8_t dRow = ROW_DELTA[dir];
		int8_t dCol = COL_DELTA[dir];

		int8_t currRow = row + dRow;
		int8_t currCol = col + dCol;

		// Loop until last matching piece
		while ((currRow < LED_ROWS) && (currRow >= 0) &&
			   (currCol < LED_COLS) && (currCol >= 0)) {
			if (leds[currRow * LED_COLS + currCol] == opposite) {
				break;
			}

			currRow += dRow;
			currCol += dCol;
		}

		// Decrease currRow & currCol to last known position
		currRow -=dRow;
		currCol -= dCol;

		dRow = -dRow;
		dCol = -dCol;

		uint8_t availCount = 0;
		uint8_t totalCount = 0;
		uint8_t continuous = 0;
		uint8_t maxContinuous = 0;

		while ((currRow < LED_ROWS) && (currRow >= 0) &&
			   (currCol < LED_COLS) && (currCol >= 0)) {

			ledMode_t mode = leds[currRow * LED_COLS + currCol];

			if (mode == opposite) {
				break;
			}

			totalCount++;

			if ((mode == player) || ((currRow == row) && (currCol == col))) {
				availCount++;
				if (++continuous > maxContinuous) {
					maxContinuous = continuous;
				}
			} else {
				// We need to check if this move is currently valid! Add an extra point if it is valid
				if (get_next_row(currCol) == currRow) {
					availCount++;
				}
				continuous = 0;
			}

			currRow += dRow;
			currCol += dCol;
		}

		availCount += (maxContinuous << 4);

		if ((totalCount >= 4) && (availCount > max)) {
			max = availCount;
		}
	}

	return max;
}

uint8_t eval_move(ledMode_t player, uint8_t col, uint8_t row)
{
	if ((col >= LED_COLS) || (row >= LED_ROWS)) {
		return 0;
	}

	ledMode_t opposition;

	if (player == LED_PLAYER1) {
		opposition = LED_PLAYER2;
	} else if (player == LED_PLAYER2) {
		opposition = LED_PLAYER1;
	} else {
		return 0;
	}

	uint8_t myScore = eval_position(player, col, row);
	uint8_t opScore = eval_position(opposition, col, row);

	if ((myScore >> 4) >= 4) {
		return 0xFF;
	} else if ((opScore >> 4) >= 4) {
		return 0xFE;
	} else if ((opScore >> 4) >= 2) {
		return myScore + opScore / 2;
	}

	return myScore;
}

uint8_t get_next_move()
{
	uint8_t max = 0;
	uint8_t sel_col = 3;

	for (uint8_t col = 0; col < LED_COLS; col++) {
		int8_t row = get_next_row(col);
		if (row < 0) {
			continue;
		}
		uint8_t val = eval_move(COMPUTER_PLAYER, col, row);
		if (val > max) {
			max = val;
			sel_col = col;
		} else if (val == max) {
			// Select the piece closest to the centre
			uint8_t centre = LED_COLS / 2;
			int8_t colDiff = centre - col;
			if (colDiff < 0) {
				colDiff = -colDiff;
			}
			int8_t selDiff = centre - sel_col;
			if (selDiff < 0) {
				selDiff = -selDiff;
			}
			if (colDiff < selDiff) {
				sel_col = col;
			}
		}
	}

	return sel_col;
}

bool has_won(uint8_t col, ledMode_t player)
{
	if (col >= LED_COLS) {
		return false;
	}

	int8_t row = get_next_row(col);

	if (row < 0) {
		row = 0;
	} else if (row < (LED_ROWS - 1)) {
		row++;
	}

	return (eval_position(player, col, row) >> 4) >= 4;
}

int8_t get_cursor()
{
	int8_t valid_col = -1;
	for (uint8_t col = 0; col < LED_COLS; col++) {
		// Check if the column has a valid number
		if (get_next_row(col) >= 0) {
			// Valid - choose if it is closer to the centre
			uint8_t centre = LED_COLS / 2;
			int8_t colDiff = centre - col;
			if (colDiff < 0) {
				colDiff = -colDiff;
			}
			int8_t selDiff = centre - valid_col;
			if (selDiff < 0) {
				selDiff = -selDiff;
			}

			if (colDiff == 0) {
				return col;
			} else if (colDiff < selDiff) {
				valid_col = col;
			}
		}
	}

	return valid_col;
}
/* USER CODE END 0 */

/**
  * @brief  The application entry point.
  * @retval int
  */
int main(void)
{

  /* MCU Configuration--------------------------------------------------------*/

  /* Reset of all peripherals, Initializes the Flash interface and the Systick. */
  HAL_Init();

  /* Configure the system clock */
  SystemClock_Config();

  /* Initialize all configured peripherals */
  MX_GPIO_Init();

  //  MX_USB_PCD_Init();
  /* USER CODE BEGIN 2 */

  driver_init();

//  colDriver_t driver = column_drivers[0];

  // Set the data
//  HAL_GPIO_WritePin(driver.dat1Port, driver.dat1Pin, 1);
//
//  HAL_Delay(1);
////  for (uint16_t i = 0; i < 1000; i++) {
////  	  NOP();
////  }
//
//  for (uint8_t i = 0; i < 17; i++) {
//	  // Toggle the clock
//	    HAL_GPIO_TogglePin(driver.clk1Port, driver.clk1Pin);
//	  //  for (uint16_t i = 0; i < 1000; i++) {
//	  //	  NOP();
//	  //  }
//	    HAL_Delay(1);
//  }


//  place_piece(LED_PLAYER1, 0);
//  place_piece(LED_PLAYER2, 0);
//  place_piece(LED_PLAYER1, 1);
//  place_piece(LED_PLAYER2, 1);
//  place_piece(LED_PLAYER1, 2);
//  place_piece(LED_PLAYER2, 2);
//  place_piece(LED_PLAYER1, 3);
//  place_piece(LED_PLAYER2, 3);
//  place_piece(LED_PLAYER1, 4);
//  place_piece(LED_PLAYER2, 4);
//  place_piece(LED_PLAYER1, 5);
//  place_piece(LED_PLAYER2, 5);
//  place_piece(LED_PLAYER1, 6);
//  place_piece(LED_PLAYER2, 6);

  uint32_t ticks = 0;

  uint8_t leftButtonCount = 0;
  uint8_t rightButtonCount = 0;
  uint8_t selectButtonCount = 0;

  gameState_t state = GAME_PLAYER1;

  int8_t blink_col = 3;
  int8_t prev_blink_col = 3;

  bool blink_on = true;

  /* USER CODE END 2 */

  /* Infinite loop */
  /* USER CODE BEGIN WHILE */

  while (ticks < (UINT32_MAX - 10))
  {
    /* USER CODE END WHILE */
	  GPIO_PinState leftButton = HAL_GPIO_ReadPin(GPIOA, GPIO_PIN_1);
	  GPIO_PinState rightButton = HAL_GPIO_ReadPin(GPIOA, GPIO_PIN_0);
	  GPIO_PinState selectButton = HAL_GPIO_ReadPin(GPIOB, GPIO_PIN_8);

	  if (leftButton == GPIO_PIN_SET) {
		  if (++leftButtonCount >= 2) {
			  leftButtonCount = 2;

			  leftButton = GPIO_PIN_RESET;
			  rightButton = GPIO_PIN_RESET;
			  selectButton = GPIO_PIN_RESET;
		  }
	  } else if (leftButtonCount > 0) {
		  if ((state == GAME_PLAYER1) && (--leftButtonCount == 0)) {
			  while (--blink_col >= 0) {
				  if (leds[blink_col] == LED_OFF) {
					  break;
				  }
			  }
			  if (blink_col < 0) {
				  blink_col = prev_blink_col;
			  } else {
				  // We have changed the blink column
				  // Clear previous blink
				  leds[prev_blink_col] = LED_OFF;
				  output_col(prev_blink_col);
				  prev_blink_col = blink_col;
			  }
		  }
	  }

	  if (rightButton == GPIO_PIN_SET) {
		  if (++rightButtonCount >= 2) {
			  rightButtonCount = 2;

			  leftButton = GPIO_PIN_RESET;
			  rightButton = GPIO_PIN_RESET;
			  selectButton = GPIO_PIN_RESET;
		  }
	  } else if (rightButtonCount > 0) {
		  if ((state == GAME_PLAYER1) && (--rightButtonCount == 0)) {
			  while (++blink_col < LED_COLS) {
				  if (leds[blink_col] == LED_OFF) {
					  break;
				  }
			  }
			  if (blink_col >= LED_COLS) {
				  blink_col = prev_blink_col;
			  } else {
				  // Clear previous blink
				  leds[prev_blink_col] = LED_OFF;
				  output_col(prev_blink_col);
				  prev_blink_col = blink_col;
			  }
		  }
	  }
	  if (selectButton == GPIO_PIN_SET) {

		  if (++selectButtonCount >= 2) {
			  selectButtonCount = 2;


			  leftButton = GPIO_PIN_RESET;
			  rightButton = GPIO_PIN_RESET;
			  selectButton = GPIO_PIN_RESET;
		  }
	  } else if (selectButtonCount > 0) {
		  if (--selectButtonCount == 0) {
			  if (state == GAME_WIN_PLAYER1 || state == GAME_WIN_PLAYER2) {
				  // Go back to start state
				  blink_col = 3;
				  prev_blink_col = 3;
				  for (uint8_t i = 0; i < LED_COUNT; i++) {
					  leds[i] = LED_OFF;
				  }
				  for (uint8_t i = 0; i < LED_COLS; i++) {
					  output_col(i);
				  }
				  state = GAME_PLAYER1;
				  winning_pieces_count = 0;
			  } else {
				  // Remove the blinking!!
				  leds[blink_col] = LED_OFF;
				  // Select the current column
				  place_piece(HUMAN_PLAYER, blink_col);

				  // Evaluate if the user has won
				  if (has_won(blink_col, HUMAN_PLAYER)) {
					  // We won
					  state = GAME_WIN_PLAYER1;
					  set_winning_pieces(HUMAN_PLAYER, blink_col);
				  } else {
					  // This is where the "computer" should make its move
					  uint8_t col = get_next_move();

					  place_piece(COMPUTER_PLAYER, col);

					  // Evaluate if the computer has won
					  if (has_won(col, COMPUTER_PLAYER)) {
						  // Computer has won
						  state = GAME_WIN_PLAYER2;
						  set_winning_pieces(COMPUTER_PLAYER, col);
					  } else {
						  // Check where the 'cursor' should be
						  int8_t cursor_pos = get_cursor();

						  if (cursor_pos < 0) {
							  // We have a tie
							  // Set the STAT LED
//							  HAL_GPIO_WritePin(GPIOB)	``
						  } else {
							  blink_col = cursor_pos;
							  prev_blink_col = cursor_pos;
						  }
					  }
				  }
			  }
		  }
	  }

	  if (ticks % 5 == 0) {
		  // Every 500ms
		  if (state == GAME_PLAYER1) {
			  // Blink on position
			  leds[blink_col] = blink_on * HUMAN_PLAYER;
			  // Output the blink
			  output_col(blink_col);
		  } else if ((state == GAME_WIN_PLAYER1) || (state == GAME_WIN_PLAYER2)) {
			  ledMode_t mode = (state == GAME_WIN_PLAYER1) ? LED_PLAYER1 : LED_PLAYER2;
			  // Flash the winning pieces
			  uint8_t refresh_bitmask = 0x00;
			  for (uint8_t i = 0; i < winning_pieces_count; i++) {
				  leds[winning_pieces[i].row * LED_COLS + winning_pieces[i].col] = mode * blink_on;
				  refresh_bitmask |= 1 << winning_pieces[i].col;
			  }

			  for (uint8_t i = 0; i < LED_COLS; i++) {
				  if (refresh_bitmask & (1 << i)) {
					  output_col(i);
				  }
			  }
		  }
		  // Change blink
		  blink_on = !blink_on;
	  }

	  HAL_Delay(100);
	  ticks++;
    /* USER CODE BEGIN 3 */
  }
  /* USER CODE END 3 */
}

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


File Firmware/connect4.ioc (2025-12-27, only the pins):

Mcu.UserName=STM32G431C8Tx
PA0.Signal=GPIO_Input
PA1.Signal=GPIO_Input
PA10.Signal=GPIO_Output
PA11.Signal=USB_DM
PA12.Signal=USB_DP
PA13.Signal=GPIO_Output
PA14.Signal=GPIO_Output
PA15.Signal=GPIO_Output
PA2.Signal=GPIO_Output
PA3.Signal=GPIO_Output
PA4.Signal=GPIO_Output
PA5.Signal=GPIO_Output
PA6.Signal=GPIO_Output
PA7.Signal=GPIO_Output
PA8.Signal=GPIO_Output
PA9.Signal=GPIO_Output
PB0.Signal=GPIO_Output
PB1.Signal=GPIO_Output
PB10.Signal=GPIO_Output
PB11.Signal=GPIO_Output
PB12.Signal=GPIO_Output
PB13.Signal=GPIO_Output
PB14.Signal=GPIO_Output
PB15.Signal=GPIO_Output
PB2.Signal=GPIO_Output
PB3.Signal=GPIO_Output
PB4.Signal=GPIO_Output
PB5.Signal=GPIO_Output
PB6.Signal=GPIO_Output
PB7.Signal=GPIO_Output
PB8-BOOT0.Signal=GPIO_Input
PB9.Signal=GPIO_Output
PC13.Signal=GPIO_Output
PC14-OSC32_IN.Signal=GPIO_Output
PC15-OSC32_OUT.Signal=GPIO_Output

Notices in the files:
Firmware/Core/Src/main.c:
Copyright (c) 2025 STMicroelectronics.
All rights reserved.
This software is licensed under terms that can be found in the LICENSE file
